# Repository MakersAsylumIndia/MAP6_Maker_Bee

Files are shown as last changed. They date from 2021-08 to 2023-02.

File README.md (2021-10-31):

# MAP6
Honey Bee shaped course ware for Maker's Asylum Electronics course.

**Maker's Asylum Project #6**

***FEATURES***

1. Two LED's with series current limit resistors
2. Two CR2032 Coin Battery or two CR2016 cells in a single 2032 holder
3. Vibration motor to move the honey bee.
4. 555 timer controls current flowing through transistor, resulting in "breathing LED" effect
5. Vibration motor intensity changes in sync with LED effect.
6. Use 555 as astable multivibrator with minor mods (see schematic)

***LEARN***

1. How to Solder
2. Resistor Color Code
3. Use of Multimeter to check LED, Resistor and Battery

SET UP A LINK -> DISCUSSION FORUM : http://discuss.makersasylum.com/t/map4-makers-asylum-learn-to-solder-badge/123

**Renders**
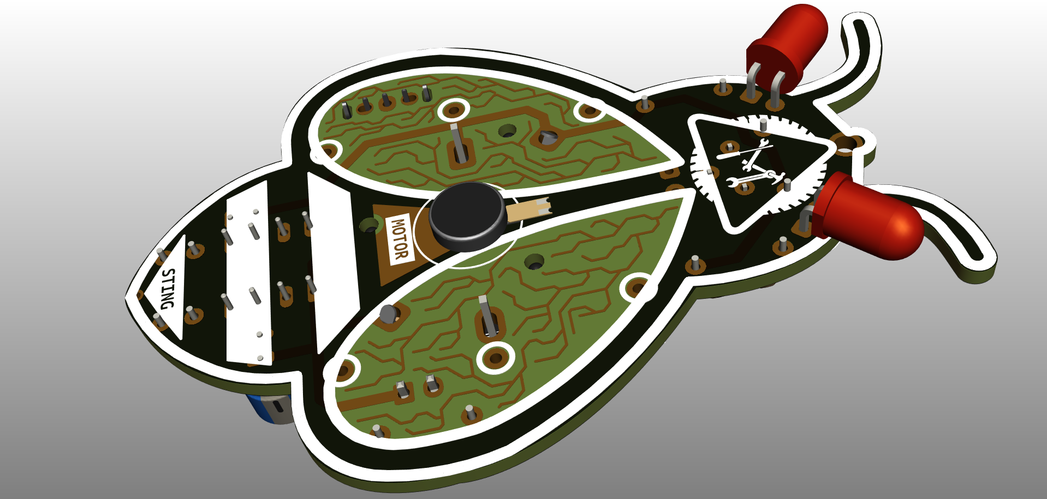
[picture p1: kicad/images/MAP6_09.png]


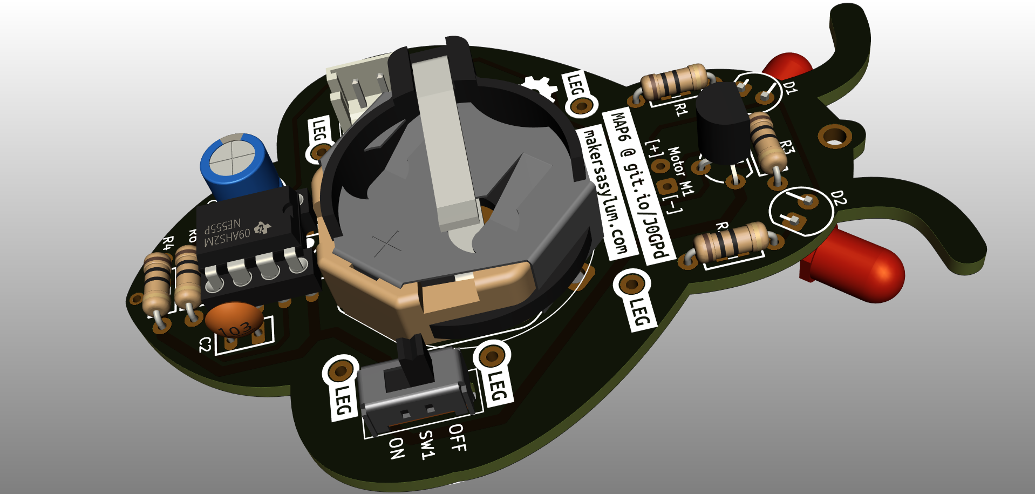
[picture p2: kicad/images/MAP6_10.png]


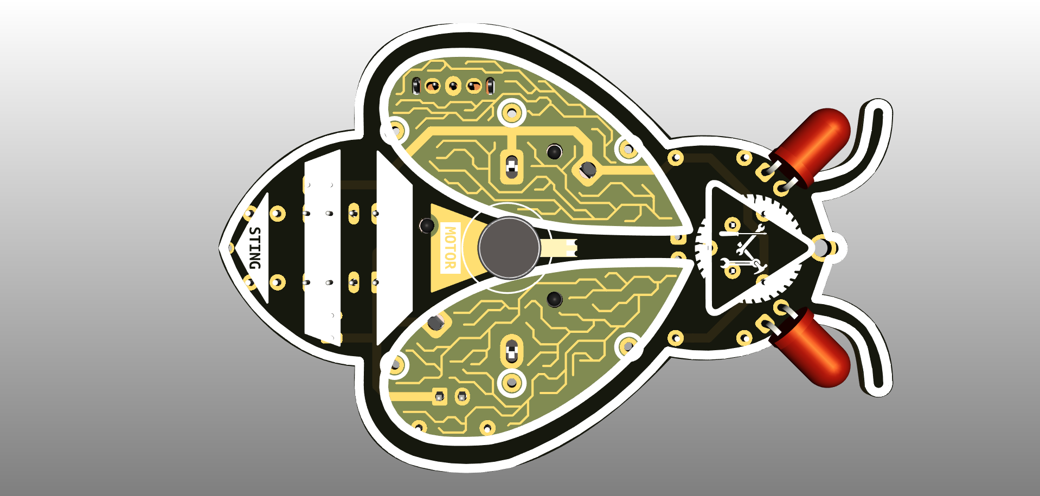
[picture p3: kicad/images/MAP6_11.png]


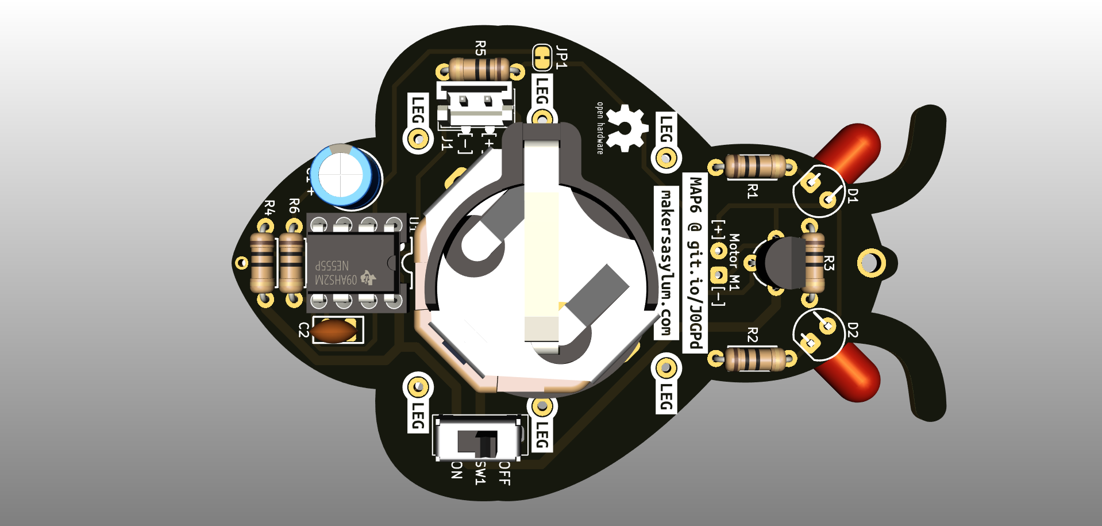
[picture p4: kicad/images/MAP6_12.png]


**Animation**
MAP6_gif

## OSHWA Certification

The **MAP6** "Maker Bee" is "Open Source Hardware" as certified by the [OSHWA](https://certification.oshwa.org/in000031.html).
OSHWA UID for the M19O2 is **IN000031**

<a href="https://certification.oshwa.org/in000031.html">OSHWA UID IN000031

License
-------

<a href="LICENSE.md">Open Source Licenses Facts</a>

[CERN Open Hardware Licence v1.2 ]

[CERN Open Hardware Licence v1.2 ]:http://www.ohwr.org/attachments/2388/cern_ohl_v_1_2.txt

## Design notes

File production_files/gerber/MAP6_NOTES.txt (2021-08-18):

1. Please place ETOK mark on BOTTOM LAYER in provided BOX.
2. SOLDER MASK COLOR : BLACK
3. LEGEND COLOR : YELLOW

OTHER REQUIREMENTS AS BELOW :

Layers 2 L
PCB Thickness(mm) 1.60 MM
PCB Dimensions 75 x 50 MM
PCBs/Panel 0
Top Solder Mask Black
Top Legend Yellow
TG Std. Tg ( 130-140 °)
Via Fill No
Carbon contacts No Carbon Contacts
Edge Connector 0.00
Blind & Buried Via NO
Electrical Testing Yes
Material FR4
Surface Finish HAL (Sn-Pb)
Start Cu Thickness 17.50
I/L Cu thickness 0.00
Finish Cu Thickness 35.00
Bottom Solder Mask Black
Bottom Legend Yellow
Layer Build-Up Standard
Peel Off No Peel Off
UL Logo No
Edge Connector Au Thickness
(μm) 0.00
Impedance Control No

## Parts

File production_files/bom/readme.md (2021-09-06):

To preview this HTML BoM directly in your browser, use this link :

https://htmlpreview.github.io/?https://github.com/MakersAsylumIndia/MAP6/blob/main/kicad/bom/MAP6_1.html

If you have already cloned the repository, you can view it in your browser locally.

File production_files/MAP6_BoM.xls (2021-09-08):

Id | Designator | Package | Quantity | Designation | NOTES | LINK | ROBU | ROBU price | Digikey P/N | Digikey price
 |  |  |  |  |  |  |  | ₹213.83 |  | ₹441.21 | @75INR/$ and 50% for shipping/customs
PCB PARTS
1 | BT1_holder |  | 1 | BAT_HOLDER | suitable for 2x2016 or 2x2032 | Option 1 (https://robu.in/product/2-x-cr2032-coin-button-cell-batteries-holder-with-on-off-switch/) | 975688 | ₹99.00
 |  |  |  |  |  | Option 2 (https://robu.in/product/cr2032-3v-button-coin-cell-battery-holder-case-box-with-on-off-switch-top-2-pcs/) | 975717
 |  |  |  |  |  | Option 3 (https://www.digikey.in/en/products/detail/mpd-memory-protection-devices/BH800S/221549) |  |  | BH800S-ND | $0.94
 |  |  |  |  |  | Option 4 (https://www.digikey.in/en/products/detail/keystone-electronics/3025-2/4499404) |  |  | 36-3025-2-ND
2 | C1 | CP_Radial_D6.3mm_P2.50mm | 1 | 47uF/16V | Capacitor, Electrolytic, 47uF, 16 V or more, 2.5 mm lead spacing, 6.3 mm diameter | LINK (https://robu.in/product/47-uf-16v-through-hole-electrolytic-capacitor-pack-of-40/) | 616602 | ₹1.12 | 732-9279-1-ND | $0.12
3 | C2 | C_Disc_D5.0mm_W2.5mm_P2.50mm | 1 | 10nF | Capacitor, Disc, 10nF, 2.5 mm lead spacing, 5 mm diameter | LINK | NA | ₹0.00 | C320C103K3G5TA-ND | $0.26
4 | D1 | LED-5MM_left | 1 | Red | Red LED, 5 mm | LINK (https://robu.in/product/everlight-5mm-red-dip-led/) | 872059 | ₹3.50 | C5SMF-RJF-CT0W0BB2CT-ND | $0.12
5 | D2 | LED-5MM_right | 1 | Red | Red LED, 5 mm | LINK (https://robu.in/product/everlight-5mm-red-dip-led/) | 872059 | ₹3.50 | C5SMF-RJF-CT0W0BB2CT-ND | $0.12
6 | M1 | motor_XDCR_C0720B001F | 1 | Motor_vibration | Vibration Motor, 10 mm | LINK (https://robu.in/product/flat-1027-mobile-phone-vibration-motor/) | 30624 | ₹82.00 | 1738-FIT0774-ND | $0.99
7 | Q1 | TO-92L_Wide | 1 | BC547 | Transistor, BC547 or equivalent NPN, TO-92 package | LINK (https://robu.in/product/bc547-npn-transistor-pack-of-20/) | 598304 | ₹1.95 | BC547ATACT-ND | $0.13
8 | R1,R2 | r_0805 | 2 | 220E | Resistor, 1/4 W, 220 E, axial or SMD | LINK (https://robu.in/product/220-ohm-resistor-0-25w-metal-film-pack-of-100/) | 582379 | ₹0.98 | CF18JT220RCT-ND | $0.02
9 | R3 | r_0805 | 1 | 47E | Resistor, 1/4 W, 47 E, axial or SMD | LINK (https://robu.in/product/47-ohm-0-25w-metal-film-resistor-pack-of-100/) | 583942 | ₹0.25 | CF18JA47R0CT-ND | $0.02
10 | R4 | r_0805 | 1 | 1k | Resistor, 1/4 W, 1k, axial or SMD | LINK (https://robu.in/product/1k-ohm-0-25w-metal-film-resistor-pack-of-100/) | 582209 | ₹0.49 | RNF18FTD1K00CT-ND | $0.03
11 | R5 | r_0805 | 1 | 33k | Resistor, 1/4 W, 33k, axial or SMD | LINK (https://robu.in/product/33k-ohm-0-25w-metal-film-resistor-pack-of-100/) | 582422 | ₹0.35 | CF18JT33K0CT-ND | $0.02
12 | R6 | r_0805 | 1 | 10k | Resistor, 1/4 W, 10k, axial or SMD | LINK (https://robu.in/product/10k-ohm-0-25w-metal-film-resistor-pack-of-100/) | 582314 | ₹0.49 | CF14JT10K0CT-ND | $0.01
13 | SW1 | SW_SPDT_Straight | 1 | On | Switch, PCB mount, or header pins with shorting link | LINK (https://robu.in/product/4mm-spdt-1p2t-slide-switch-pack-of-10/) | 578531 | ₹4.90 | CKN9565-ND | $0.41
14 | U1 | DIP-8_W7.62mm | 1 | LM555 | IC, LM555, DPI package | LINK (https://robu.in/product/ne-555-p-pdip-8-timer-ic-pack-of-5/) | 161997 | ₹9.80 | ICM7555IPAZ-ND | $0.59
15 | U1_socket | DIP-8_W7.62mm | 1 | DIP-8 socket | Socket for 8-pin DIP-8 package | LINK (https://robu.in/product/8-pin-dip-ic-socket-base-adaptor-pack-of-10/) | 534647 | ₹5.50 | AE9986-ND | $0.13
OTHER PARTS
16 | BT1 | cr2032_02 | 2 | BAT | Use 2 nos 2032 | LINK (https://robu.in/product/panasonic-cr2032-3v-lithium-coin-battery-2pcs/) | 352755 | ₹39.50
17 | LEGS | Brass Wire, 0.8 ~ 0.9 mm | 6 | -- | 6 pieces, each about 3-4 inches long | Amazon (https://www.amazon.in/s?k=Brass+Jewellery+Wire&ref=nb_sb_noss)

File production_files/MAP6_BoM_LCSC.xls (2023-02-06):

Quantity | Manufacture Part Number | Manufacturer(optional) | Description(optional) | LCSC Part Number(optional) | Package(optional) | Customer Part Number(optional)
1 | KM476M035E11RR0VH2FP0
1 | CC1H103ZA1FD3F4D1001
2 | XL-502SURD
1 | LCM1027A2445F
1 | BC547CBK
2 | MFR-25FTE52-220R
1 | MFR2WSFTE73-47R
1 | MFR50SFTE52-1K
1 | MFR-25JT-52-33K
1 | MFR-25FTE52-10K
1 | SS-12D02G3
1 | NE555L-D08-T
1 | DS1009-08AT1NX-0A2

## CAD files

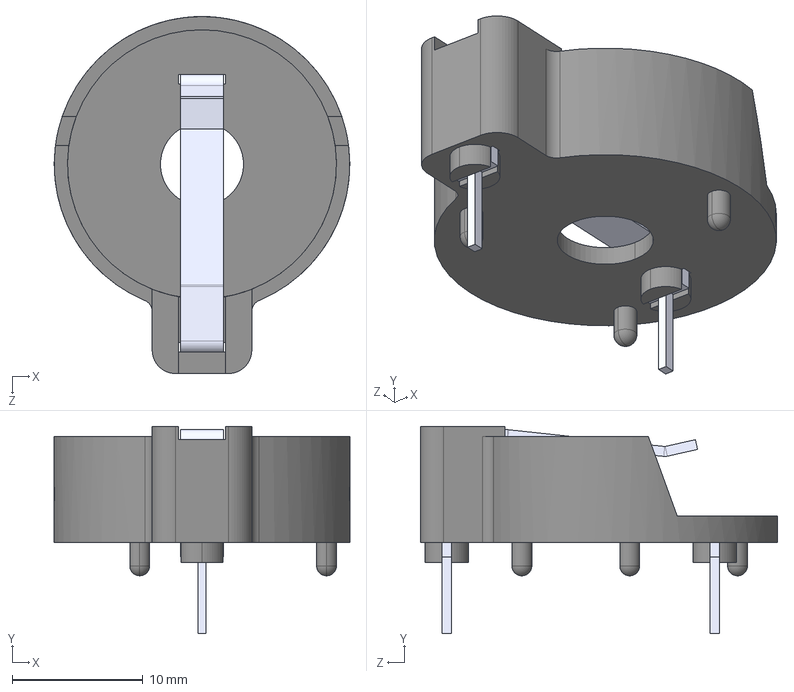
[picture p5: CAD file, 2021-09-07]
datasheets/BH800S/BH800S.step
22.6 x 15.8 x 27.3 mm

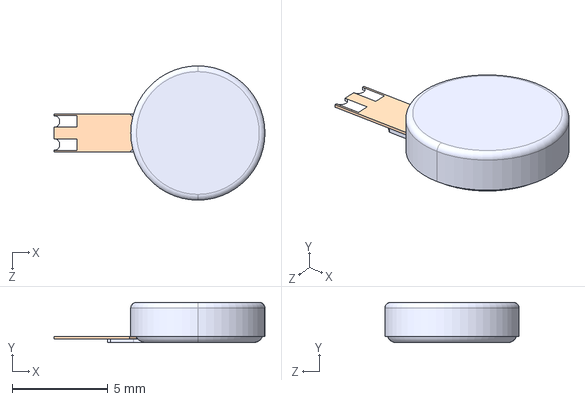
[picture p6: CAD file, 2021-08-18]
datasheets/C0720B001F/C0720B001F.step
11.0 x 2.10 x 7.00 mm

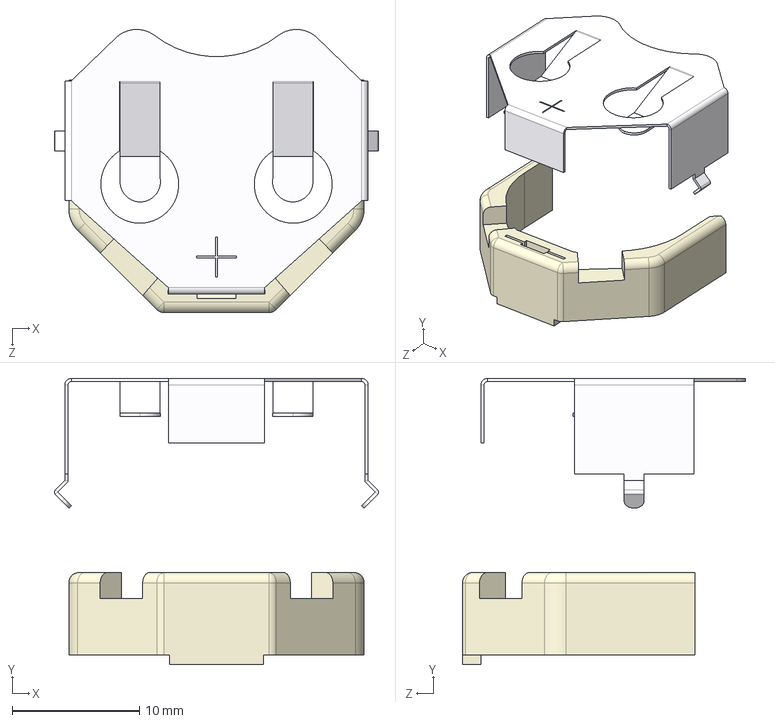
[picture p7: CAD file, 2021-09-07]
datasheets/keystone-PN3025-2.step
25.5 x 22.5 x 22.3 mm

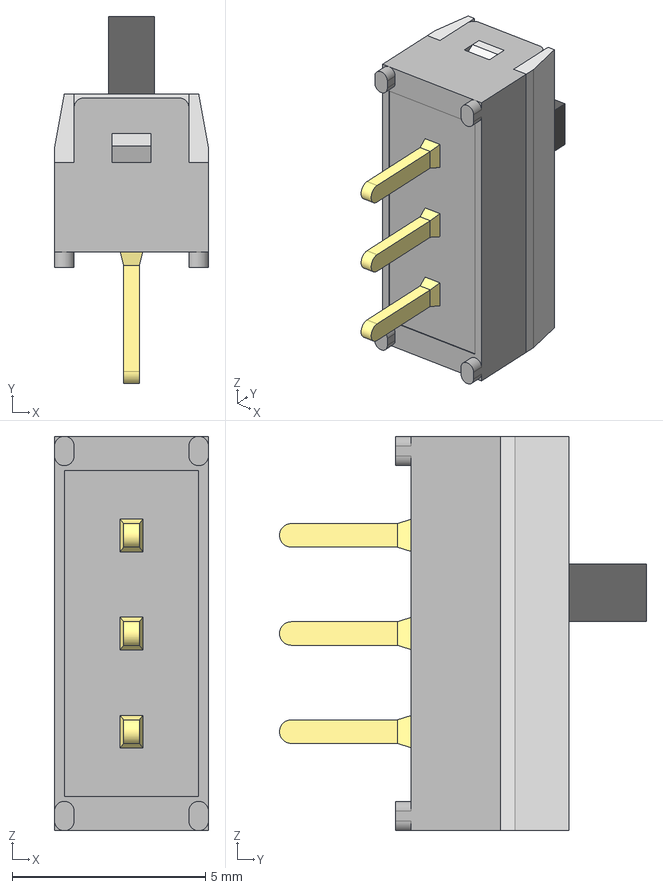
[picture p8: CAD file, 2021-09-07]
datasheets/NKKSWITCHES_SS12SDP4/SS12SDP4.stp
3.99 x 9.50 x 10.2 mm
_SS12SDP4body2
_SS12SDP4trmd
_SS12SDP4body1
_SS12SDP4actut

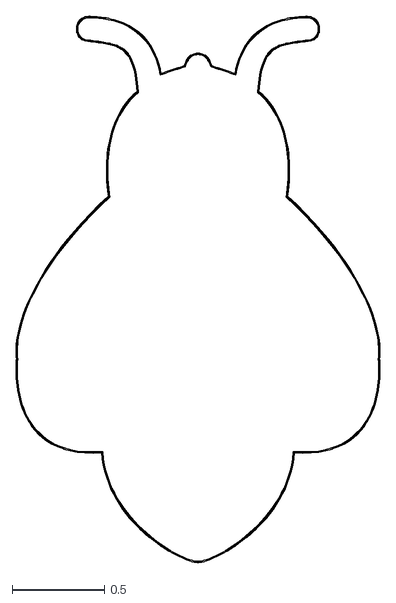
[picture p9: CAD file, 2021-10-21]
fabricate/dxf_files/MAP6-Edge_Cuts.dxf
1.97 x 2.95

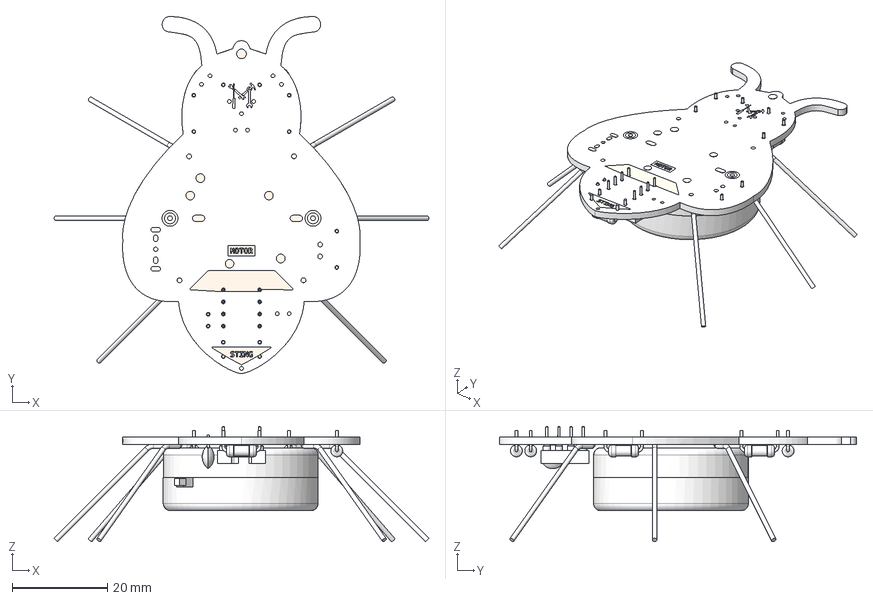
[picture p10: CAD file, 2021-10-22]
fabricate/MAP6_CAD2.FCStd
78.6 x 74.9 x 24.2 mm
Pcb_25ad
topSilks_fa88
botSilks_3b4e
C2_C_Disc_D50mm_W25mm_P250mm001_6139262A
DIP_8_W762mm_Socket
Top

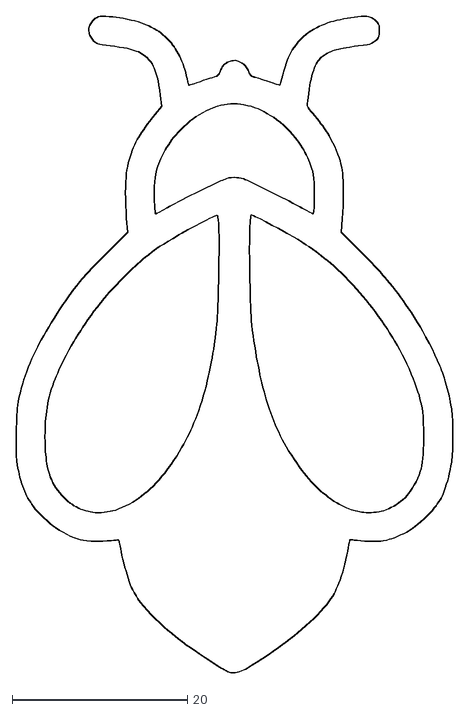
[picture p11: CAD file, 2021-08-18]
fabricate/PCB_outline/shape_bee6.dxf
49.8 x 74.9

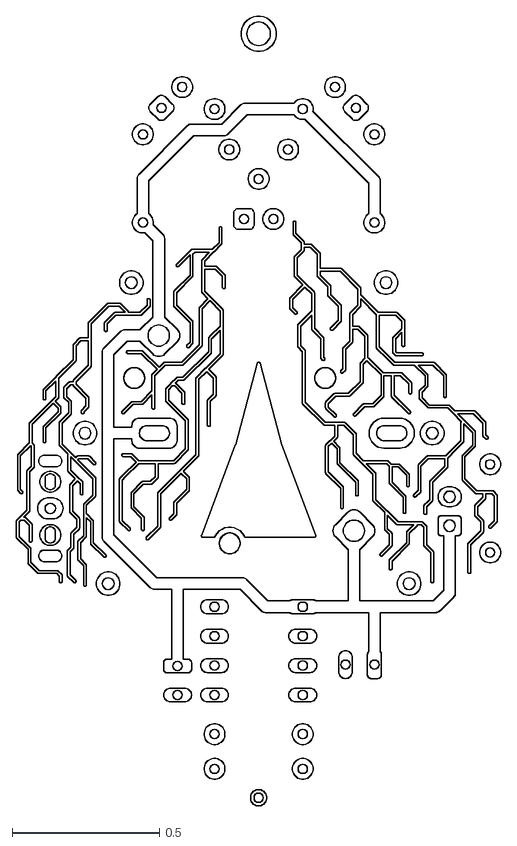
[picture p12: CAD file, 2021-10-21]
fabricate/dxf_files/MAP6-F_Cu.dxf
1.65 x 2.69

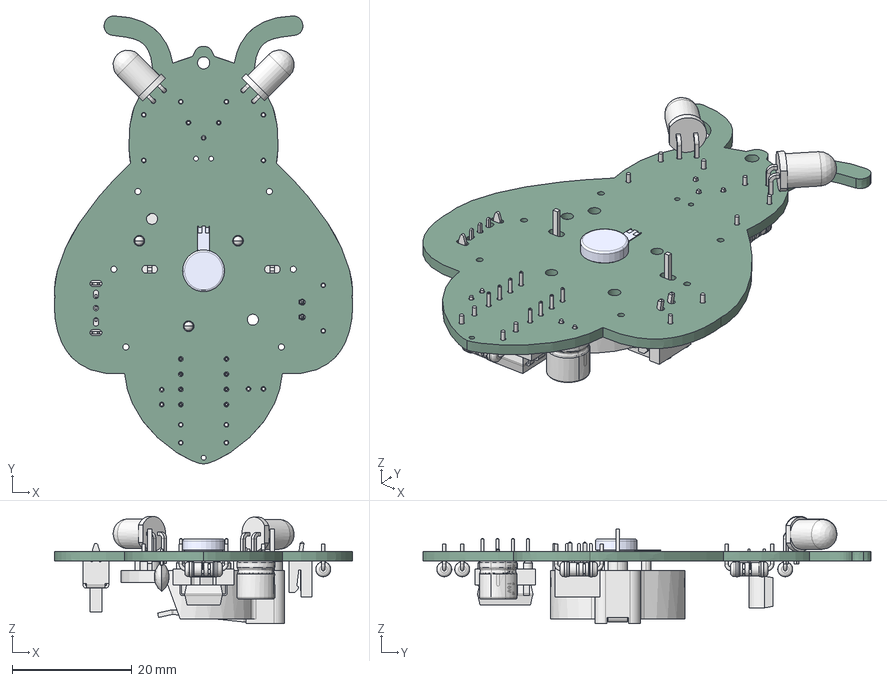
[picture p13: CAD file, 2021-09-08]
fabricate/MAP6_CAD.FCStd
49.9 x 74.9 x 17.9 mm
Pcb_25ad
C0720B001F
C0720B001F001
C0720B001F002
C0720B001F003
C0720B001F004
C1_CP_Radial_D63mm_P250mm001_6139076A
C2_C_Disc_D50mm_W25mm_P250mm001_6139262A
U1_DIP-8_W7.62mm_611AD7C5
J1_JST_B2B_EH_A_61394347

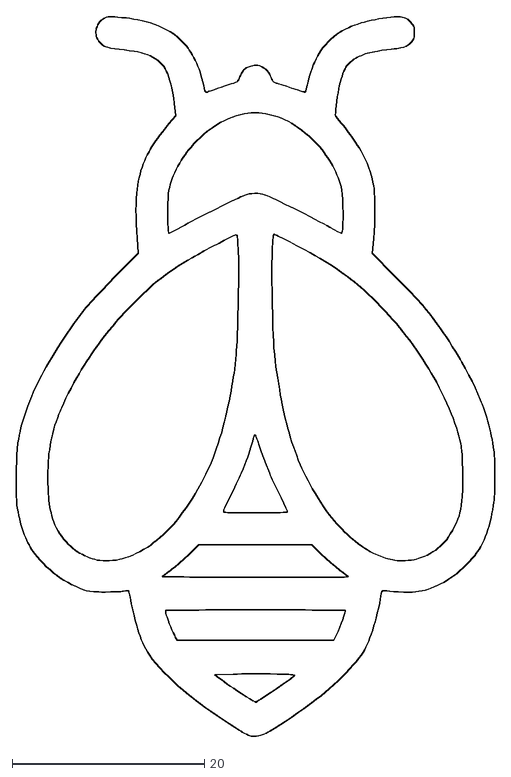
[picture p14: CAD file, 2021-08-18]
fabricate/PCB_outline/shape_bee.dxf
49.8 x 74.9

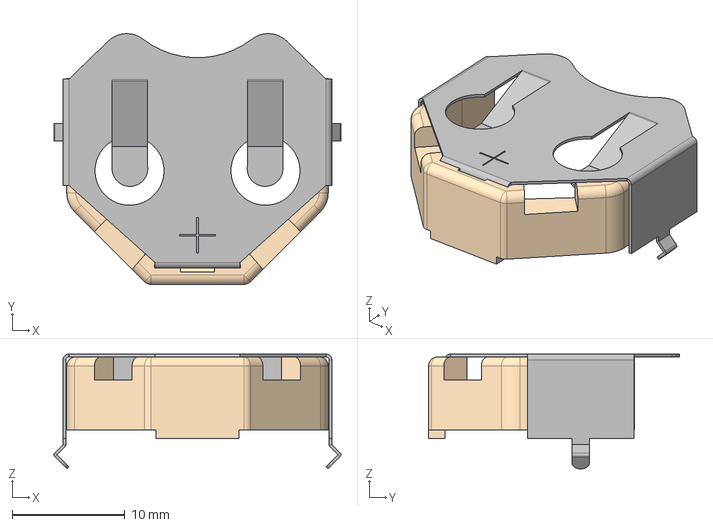
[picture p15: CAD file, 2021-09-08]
kicad/3d_modules/CR2032_3025-2.step
25.5 x 22.3 x 10.2 mm

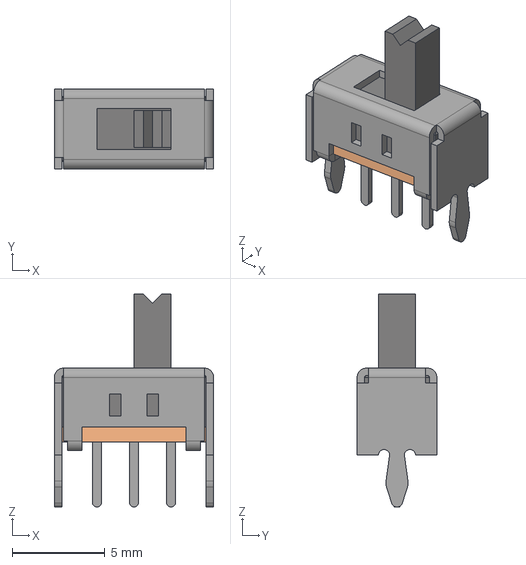
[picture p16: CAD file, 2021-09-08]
nightly/3d_modules/SW_OS102011MS2QN007.step
8.60 x 4.30 x 11.5 mm

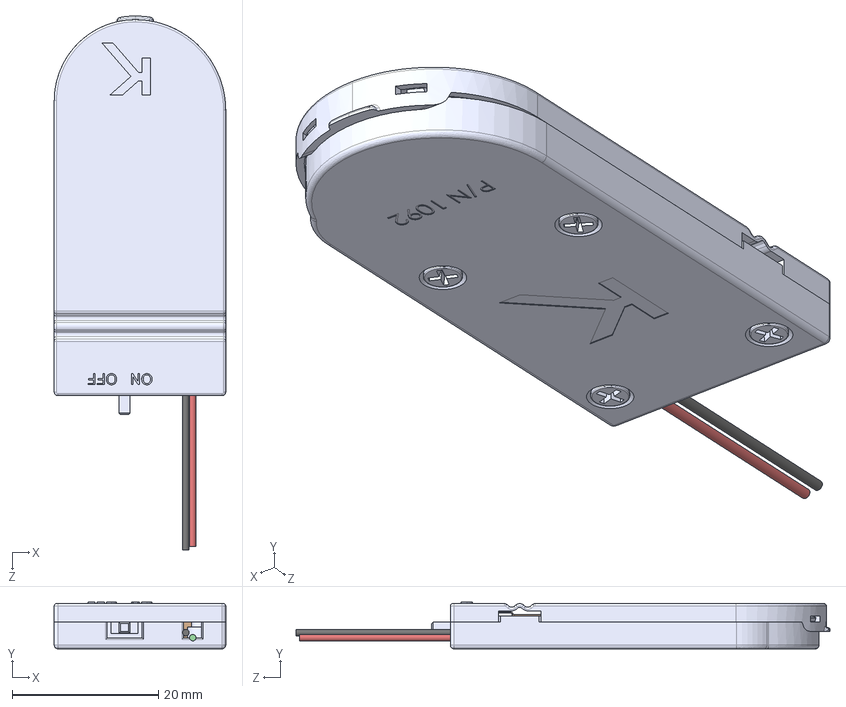
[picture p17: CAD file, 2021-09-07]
datasheets/keystone-PN1092.step
23.5 x 6.40 x 73.1 mm
SCREW-2032______ANY_ANY_ANY x 4
1092_switch-1.SLDASM
1092_switch-2
F1092-2
F1092-1
1092_base
1092_cover
F1092-3
26 AWG BLACK WIRE for 1086
26 AWG RED WIRE ror 1086

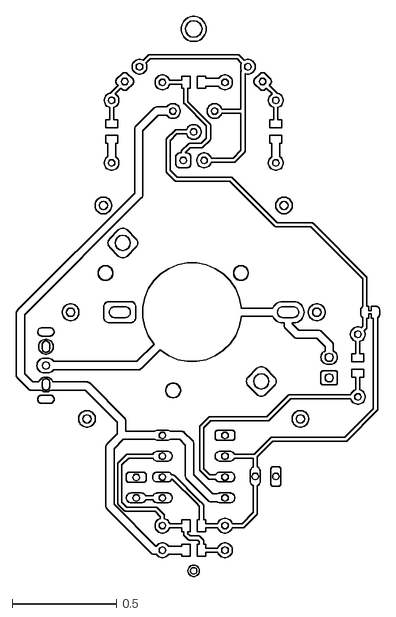
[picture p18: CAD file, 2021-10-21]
fabricate/dxf_files/MAP6-B_Cu.dxf
1.74 x 2.69

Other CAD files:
kicad/3d_modules/CR2032_BH800S.step
nightly/3d_modules/CR2032_BH800S.step
fabricate/PCB_outline/shape_bee5.dxf
datasheets/OS102011MS2QN1/OS102011MS2QN1.step
fabricate/PCB_outline/outline_bee.dxf
fabricate/PCB_outline/outline_bee2.dxf
fabricate/PCB_outline/shape_bee2.dxf
fabricate/PCB_outline/shape_bee3.dxf
fabricate/PCB_outline/shape_bee4.dxf
fabricate/dxf_files/MAP6-B_Mask.dxf
fabricate/dxf_files/MAP6-B_SilkS.dxf
fabricate/dxf_files/MAP6-F_Mask.dxf
fabricate/dxf_files/MAP6-F_SilkS.dxf
kicad/3d_modules/CR2032_cyl_cp.step
kicad/3d_modules/JST_EH_B2B-EH-A_1x02_P2.50mm_Vertical.step
kicad/3d_modules/SW_SS12SDP4.step
nightly/3d_modules/2x2032_cyl.FCStd
nightly/3d_modules/2x2032_cyl.step
nightly/3d_modules/BATTERY_HOLDER_CR2032.step
nightly/3d_modules/CP_Radial_D63mm_P250mm.step
nightly/3d_modules/CP_Radial_D63mm_P250mm_FC.step
nightly/3d_modules/CP_Radial_D63mm_P25mm.FCStd
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

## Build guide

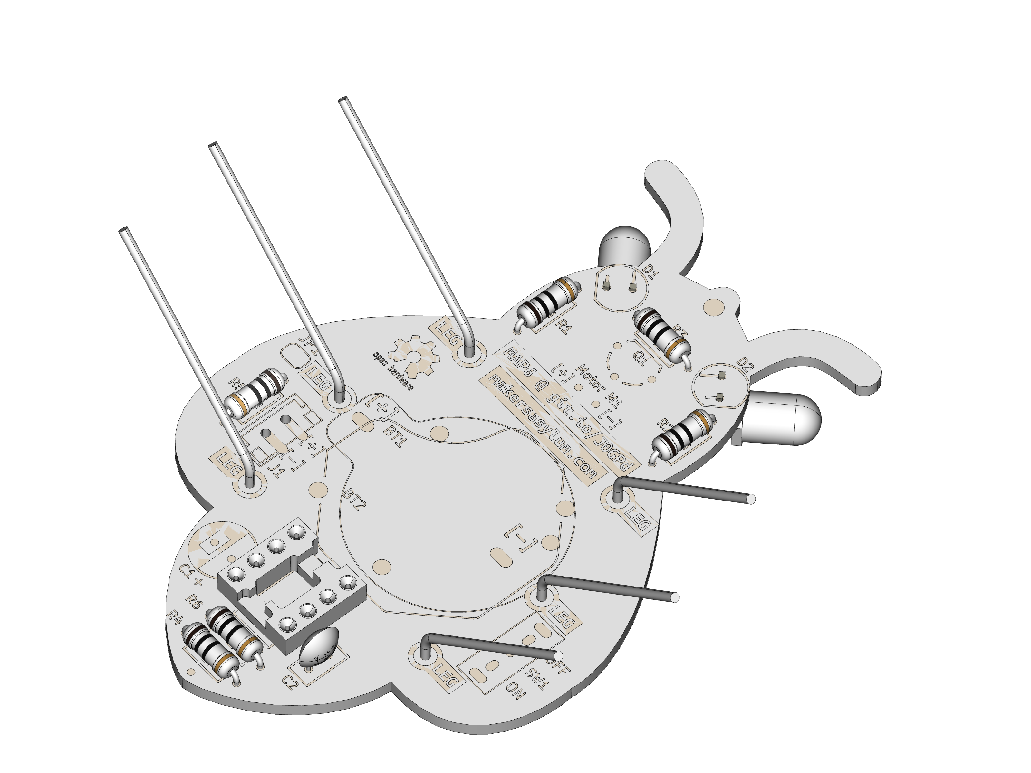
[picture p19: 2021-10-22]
fabricate/images/MAP6_assy_23.png

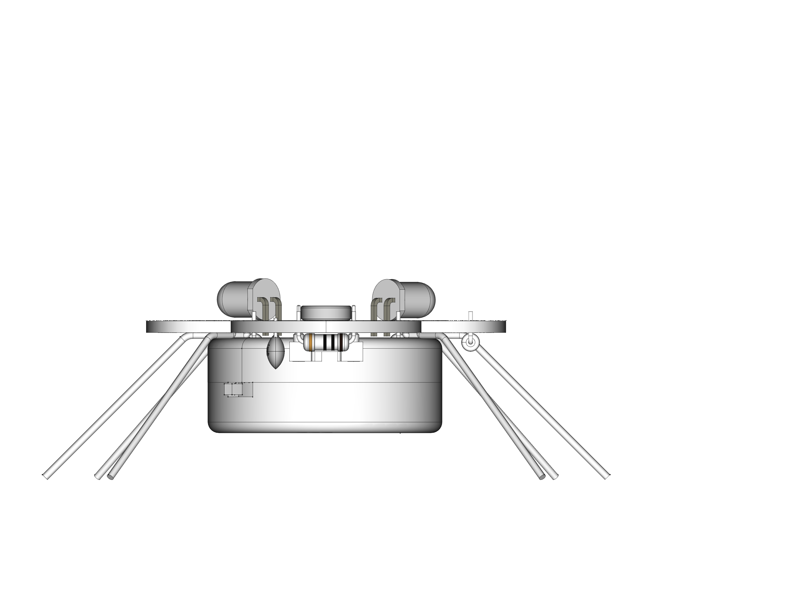
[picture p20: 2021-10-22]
fabricate/images/MAP6_assy_31.png

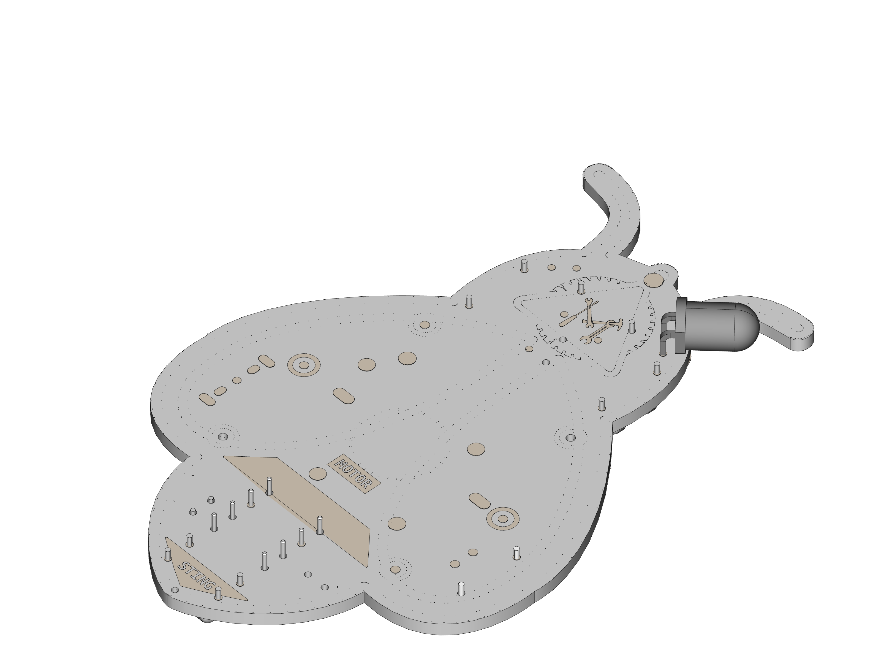
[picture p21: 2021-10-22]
fabricate/images/MAP6_assy_16.png

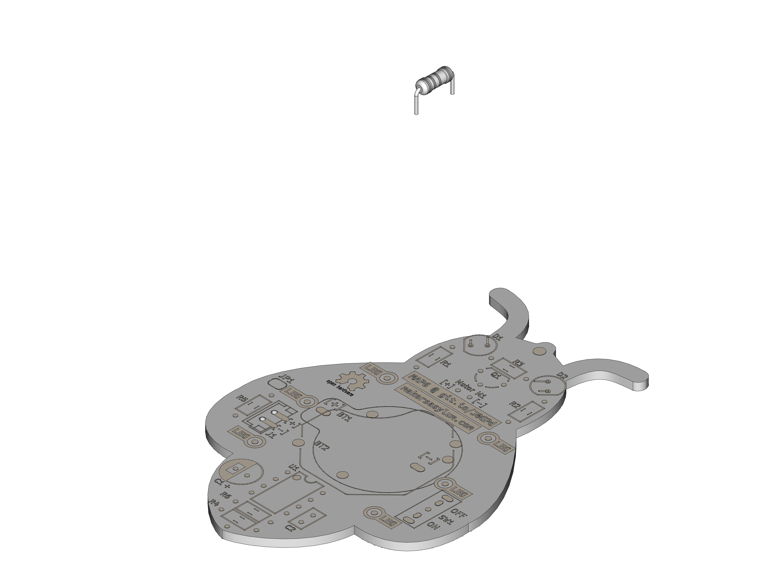
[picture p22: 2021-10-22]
fabricate/images/MAP6_assy_02.png

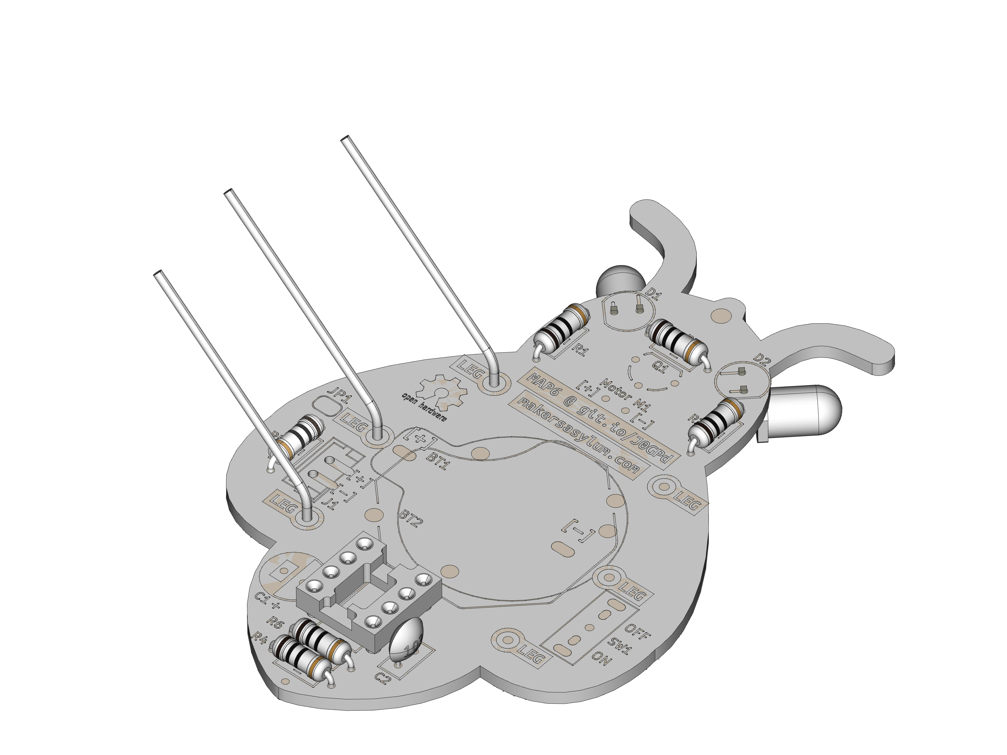
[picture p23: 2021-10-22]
fabricate/images/MAP6_assy_22.png

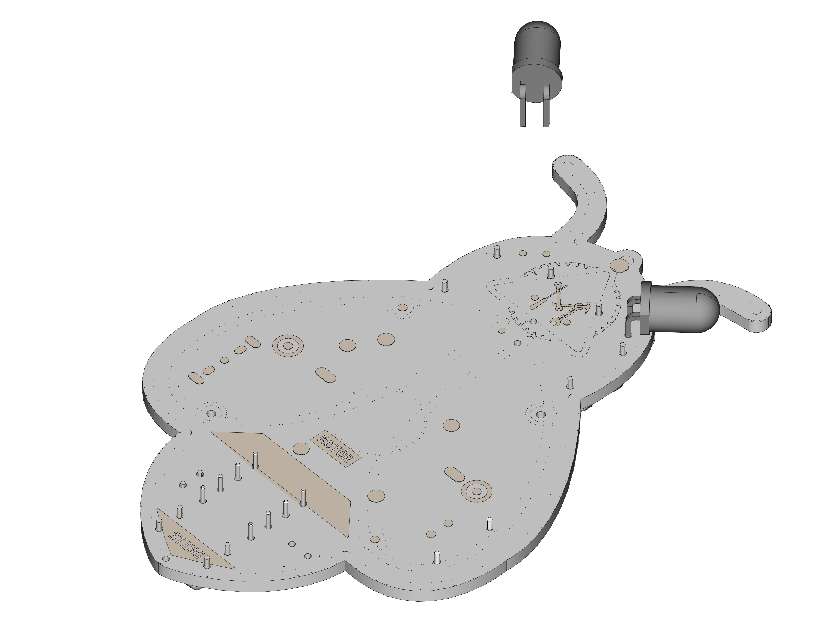
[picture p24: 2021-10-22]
fabricate/images/MAP6_assy_17.png

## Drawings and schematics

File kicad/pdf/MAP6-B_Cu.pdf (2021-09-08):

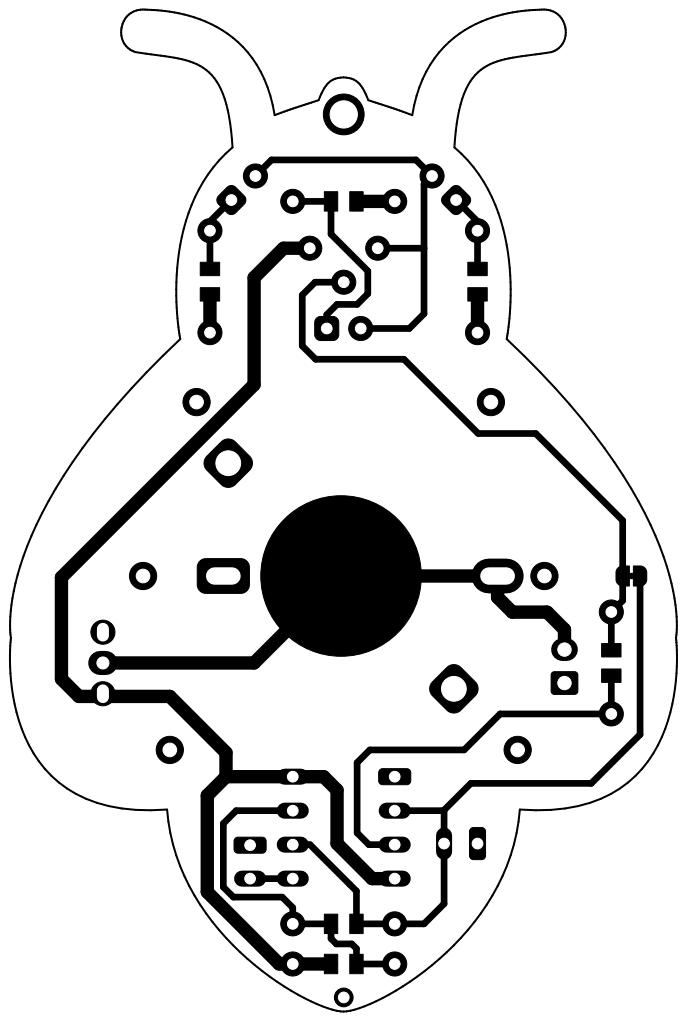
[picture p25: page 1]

Learn to Solder Maker's Asylum Badge
File: MAP6.kicad_pcb Sheet: Maker's Asylum

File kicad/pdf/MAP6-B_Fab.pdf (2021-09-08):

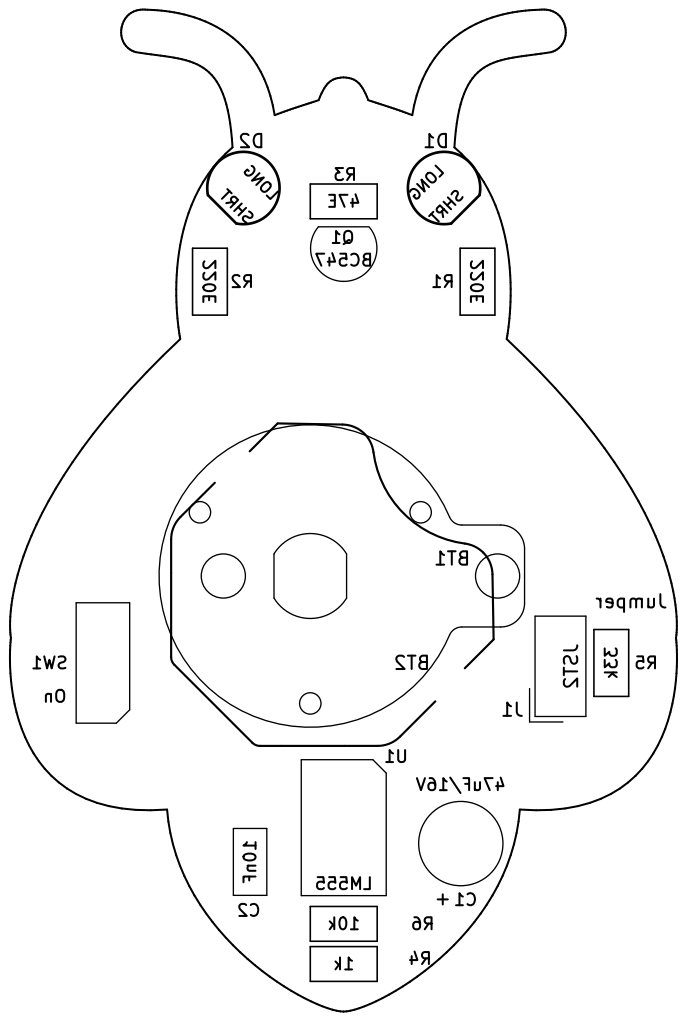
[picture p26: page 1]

Learn to Solder Maker's Asylum Badge
File: MAP6.kicad_pcb Sheet: Maker's Asylum

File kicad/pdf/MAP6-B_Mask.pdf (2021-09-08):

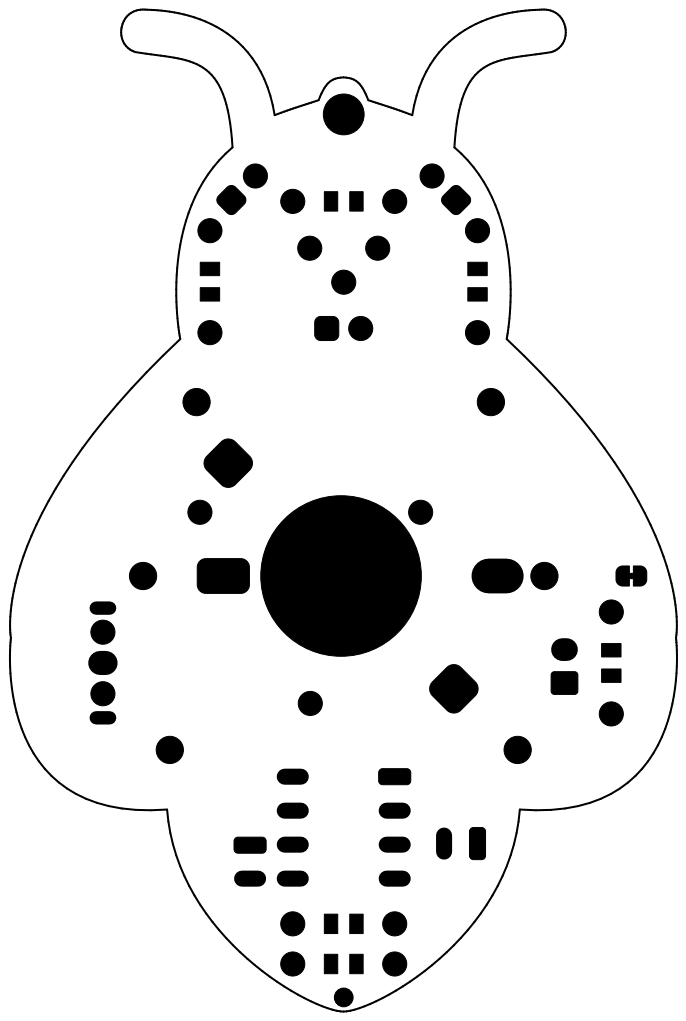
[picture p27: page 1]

Learn to Solder Maker's Asylum Badge
File: MAP6.kicad_pcb Sheet: Maker's Asylum

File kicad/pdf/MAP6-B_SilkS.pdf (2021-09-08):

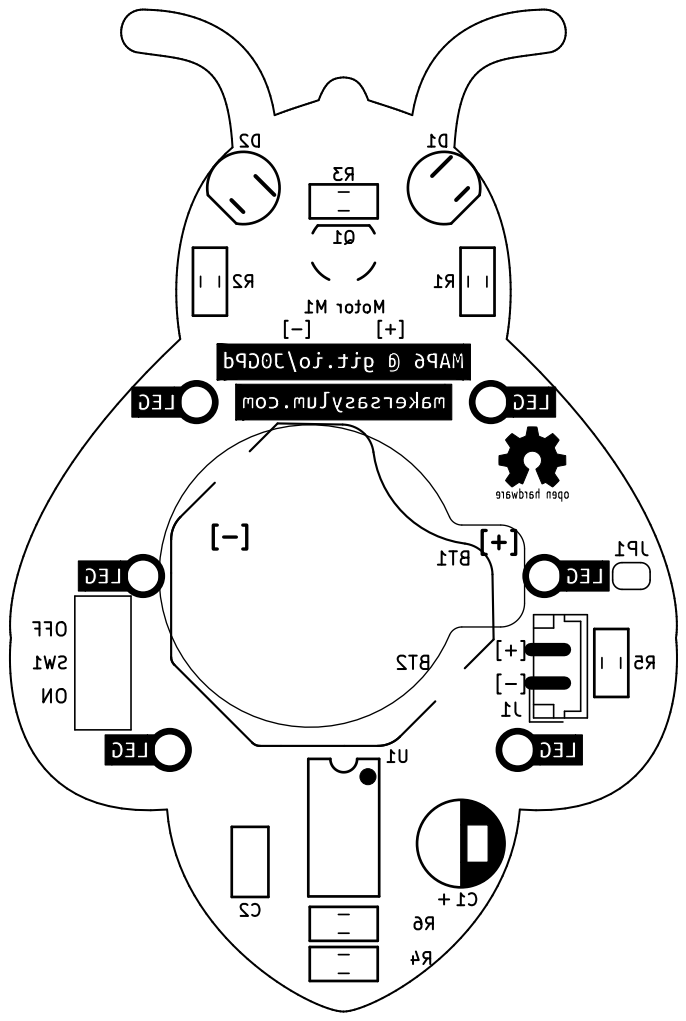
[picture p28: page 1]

Learn to Solder Maker's Asylum Badge
File: MAP6.kicad_pcb Sheet: Maker's Asylum

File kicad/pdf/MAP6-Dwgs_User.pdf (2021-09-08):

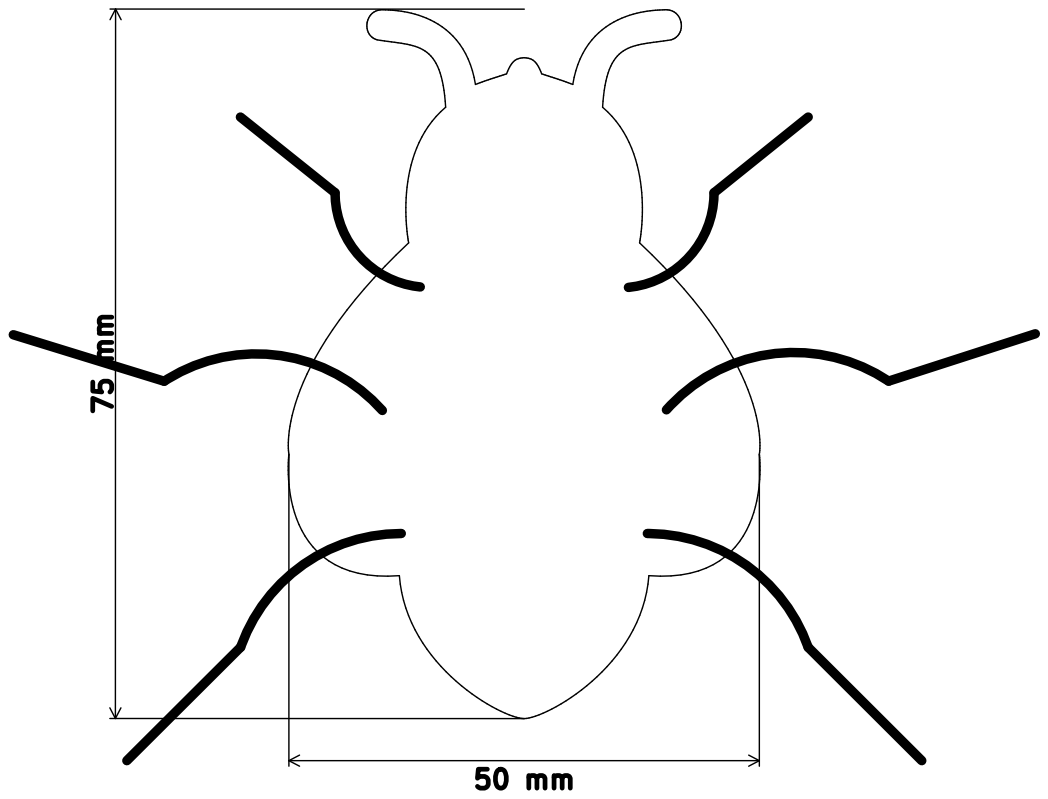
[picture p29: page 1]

Learn to Solder Maker's Asylum Badge 75 mm

File: MAP6.kicad_pcb Sheet: Maker's Asylum

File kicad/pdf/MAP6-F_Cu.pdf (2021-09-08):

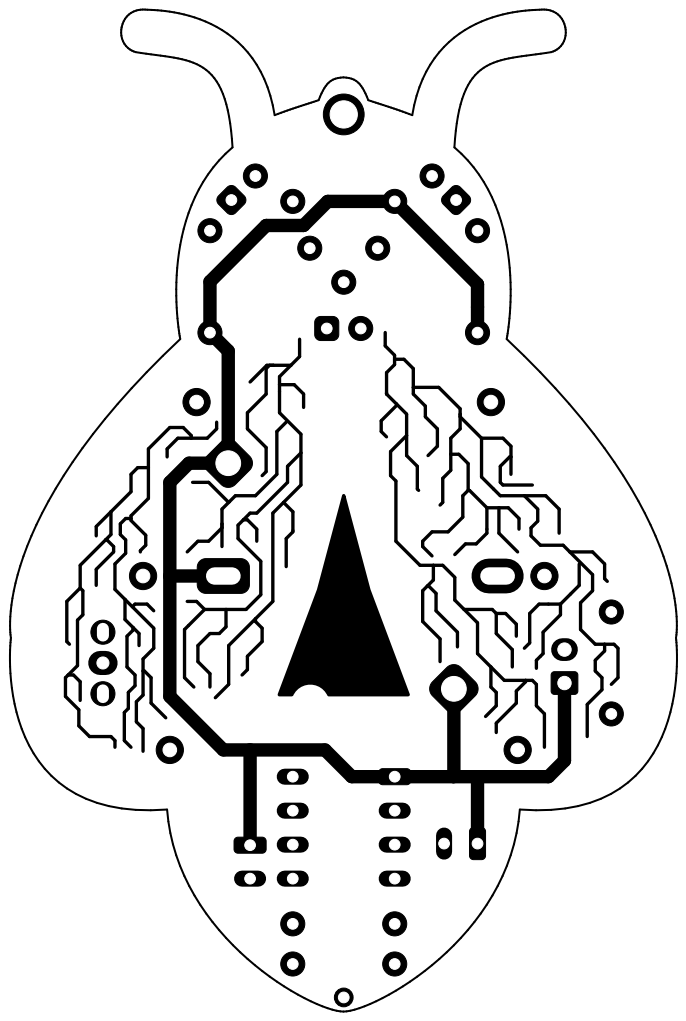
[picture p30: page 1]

Learn to Solder Maker's Asylum Badge
File: MAP6.kicad_pcb Sheet: Maker's Asylum

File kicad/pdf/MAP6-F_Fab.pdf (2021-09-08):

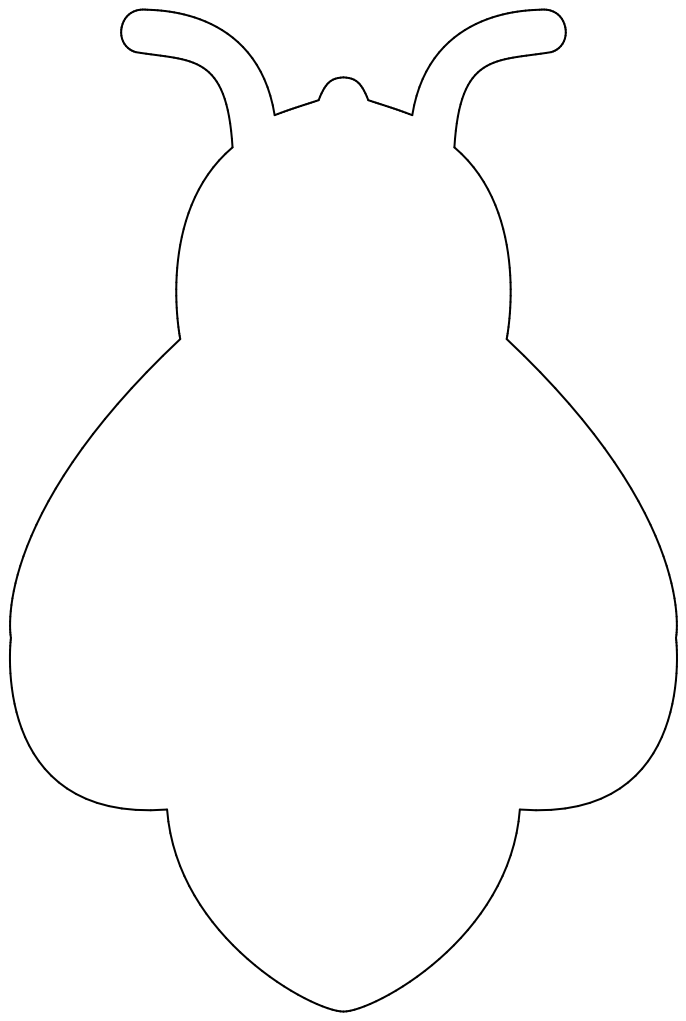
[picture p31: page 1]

Learn to Solder Maker's Asylum Badge
File: MAP6.kicad_pcb Sheet: Maker's Asylum

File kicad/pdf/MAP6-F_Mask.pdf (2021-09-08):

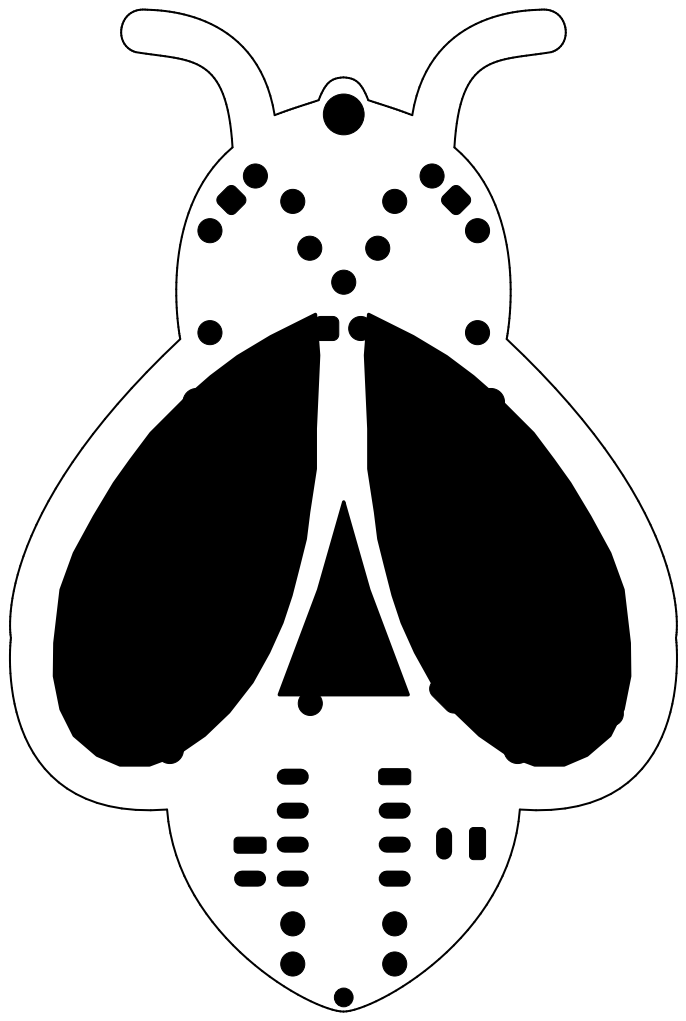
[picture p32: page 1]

Learn to Solder Maker's Asylum Badge
File: MAP6.kicad_pcb Sheet: Maker's Asylum

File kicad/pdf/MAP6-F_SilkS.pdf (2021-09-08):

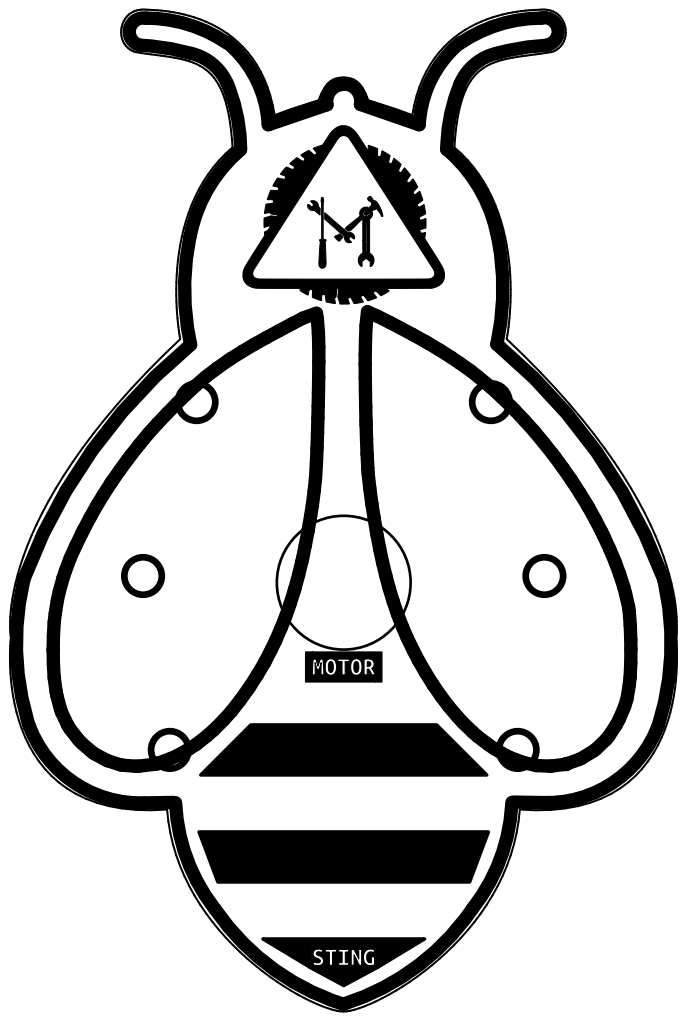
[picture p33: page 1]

Learn to Solder Maker's Asylum Badge
File: MAP6.kicad_pcb Sheet: Maker's Asylum

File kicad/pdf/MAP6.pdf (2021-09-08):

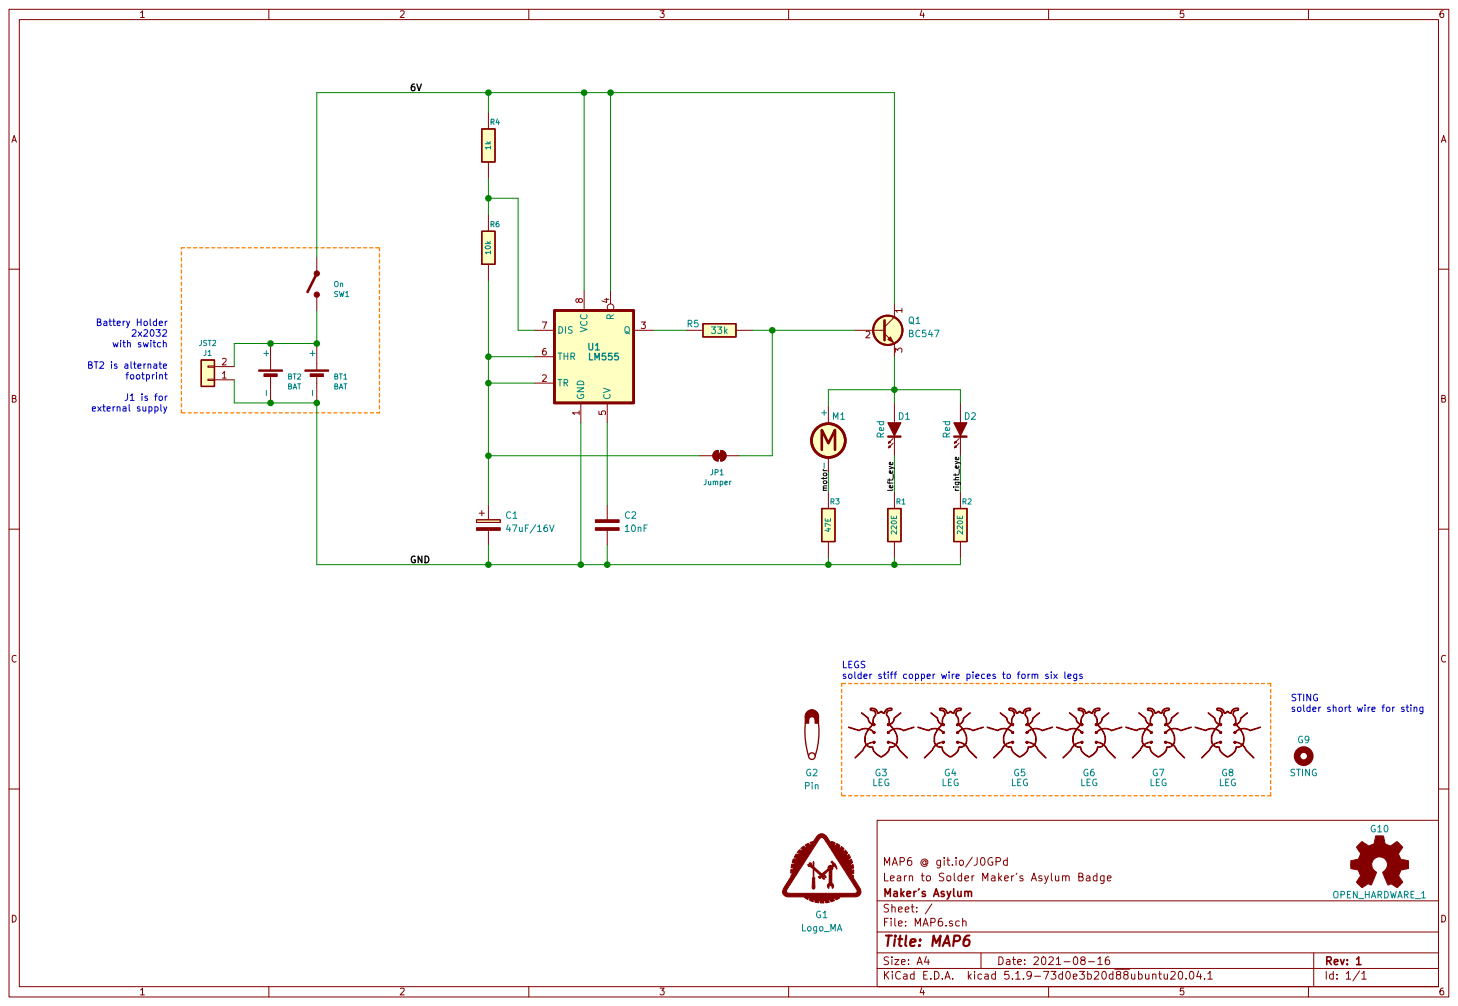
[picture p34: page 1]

Battery Holder 2x2032 with switch BT2 is alternate

solder stiff copper wire pieces to form six legs

solder short wire for sting

Learn to Solder Maker's Asylum Badge
File: MAP6.sch Sheet: / Maker's Asylum

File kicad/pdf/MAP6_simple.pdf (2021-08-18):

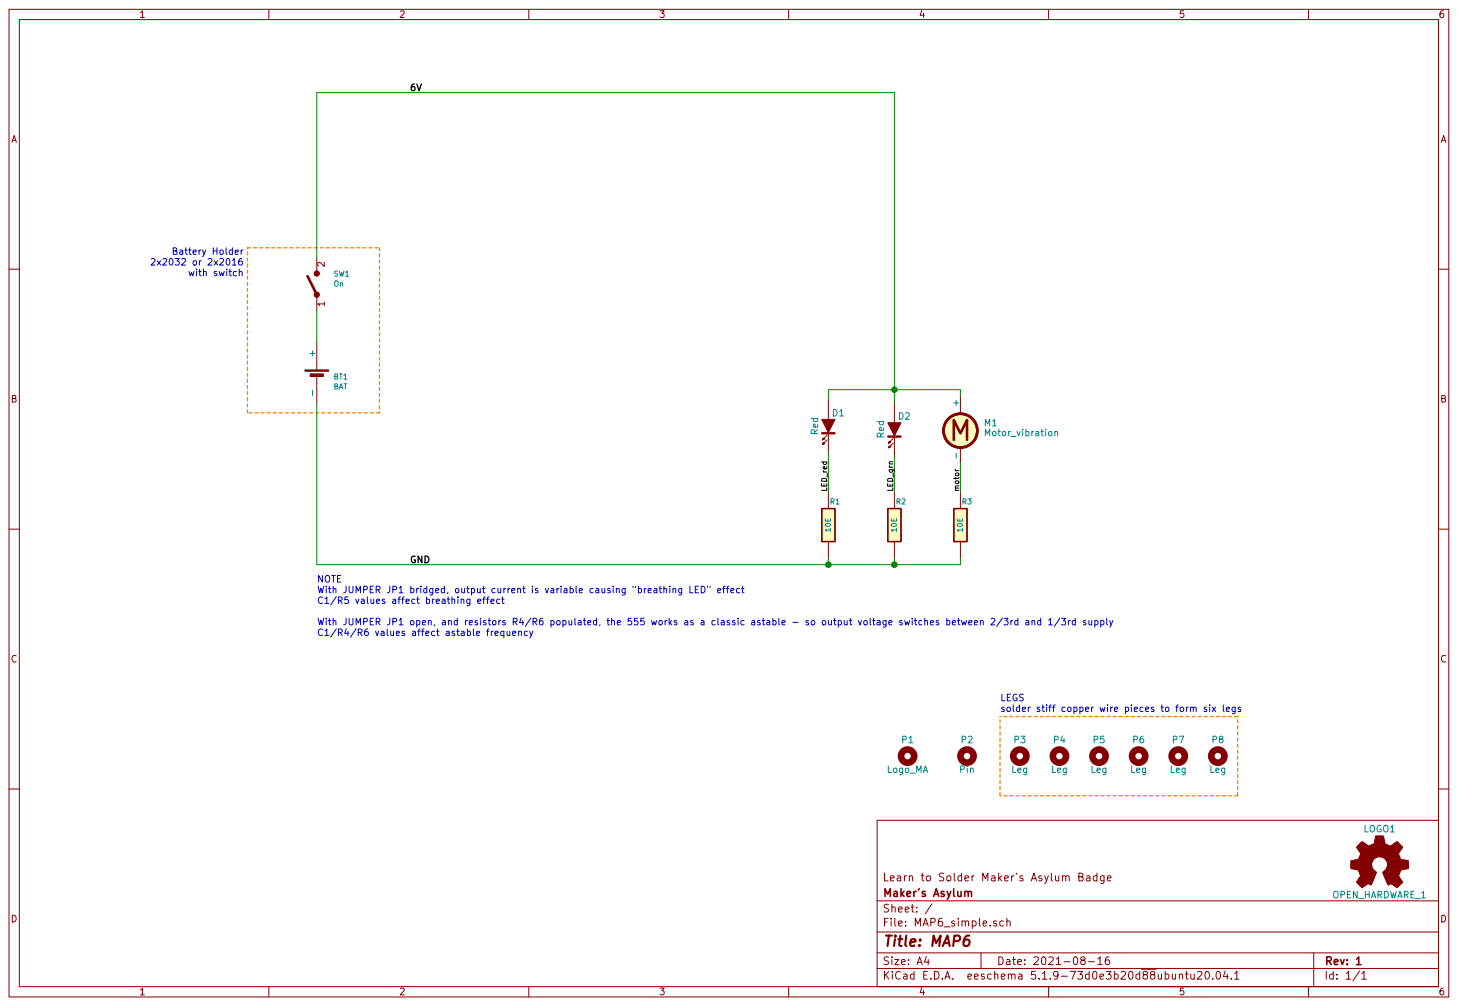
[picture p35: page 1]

Battery Holder 2x2032 or 2x2016 with switch

solder stiff copper wire pieces to form six legs NOTE With JUMPER JP1 bridged, output current is variable causing "breathing LED" effect

C1/R5 values affect breathing effect

With JUMPER JP1 open, and resistors R4/R6 populated, the 555 works as a classic astable - so output voltage switches between 2/3rd and 1/3rd supply
C1/R4/R6 values affect astable frequency

Learn to Solder Maker's Asylum Badge
File: MAP6_simple.sch Sheet: / Maker's Asylum

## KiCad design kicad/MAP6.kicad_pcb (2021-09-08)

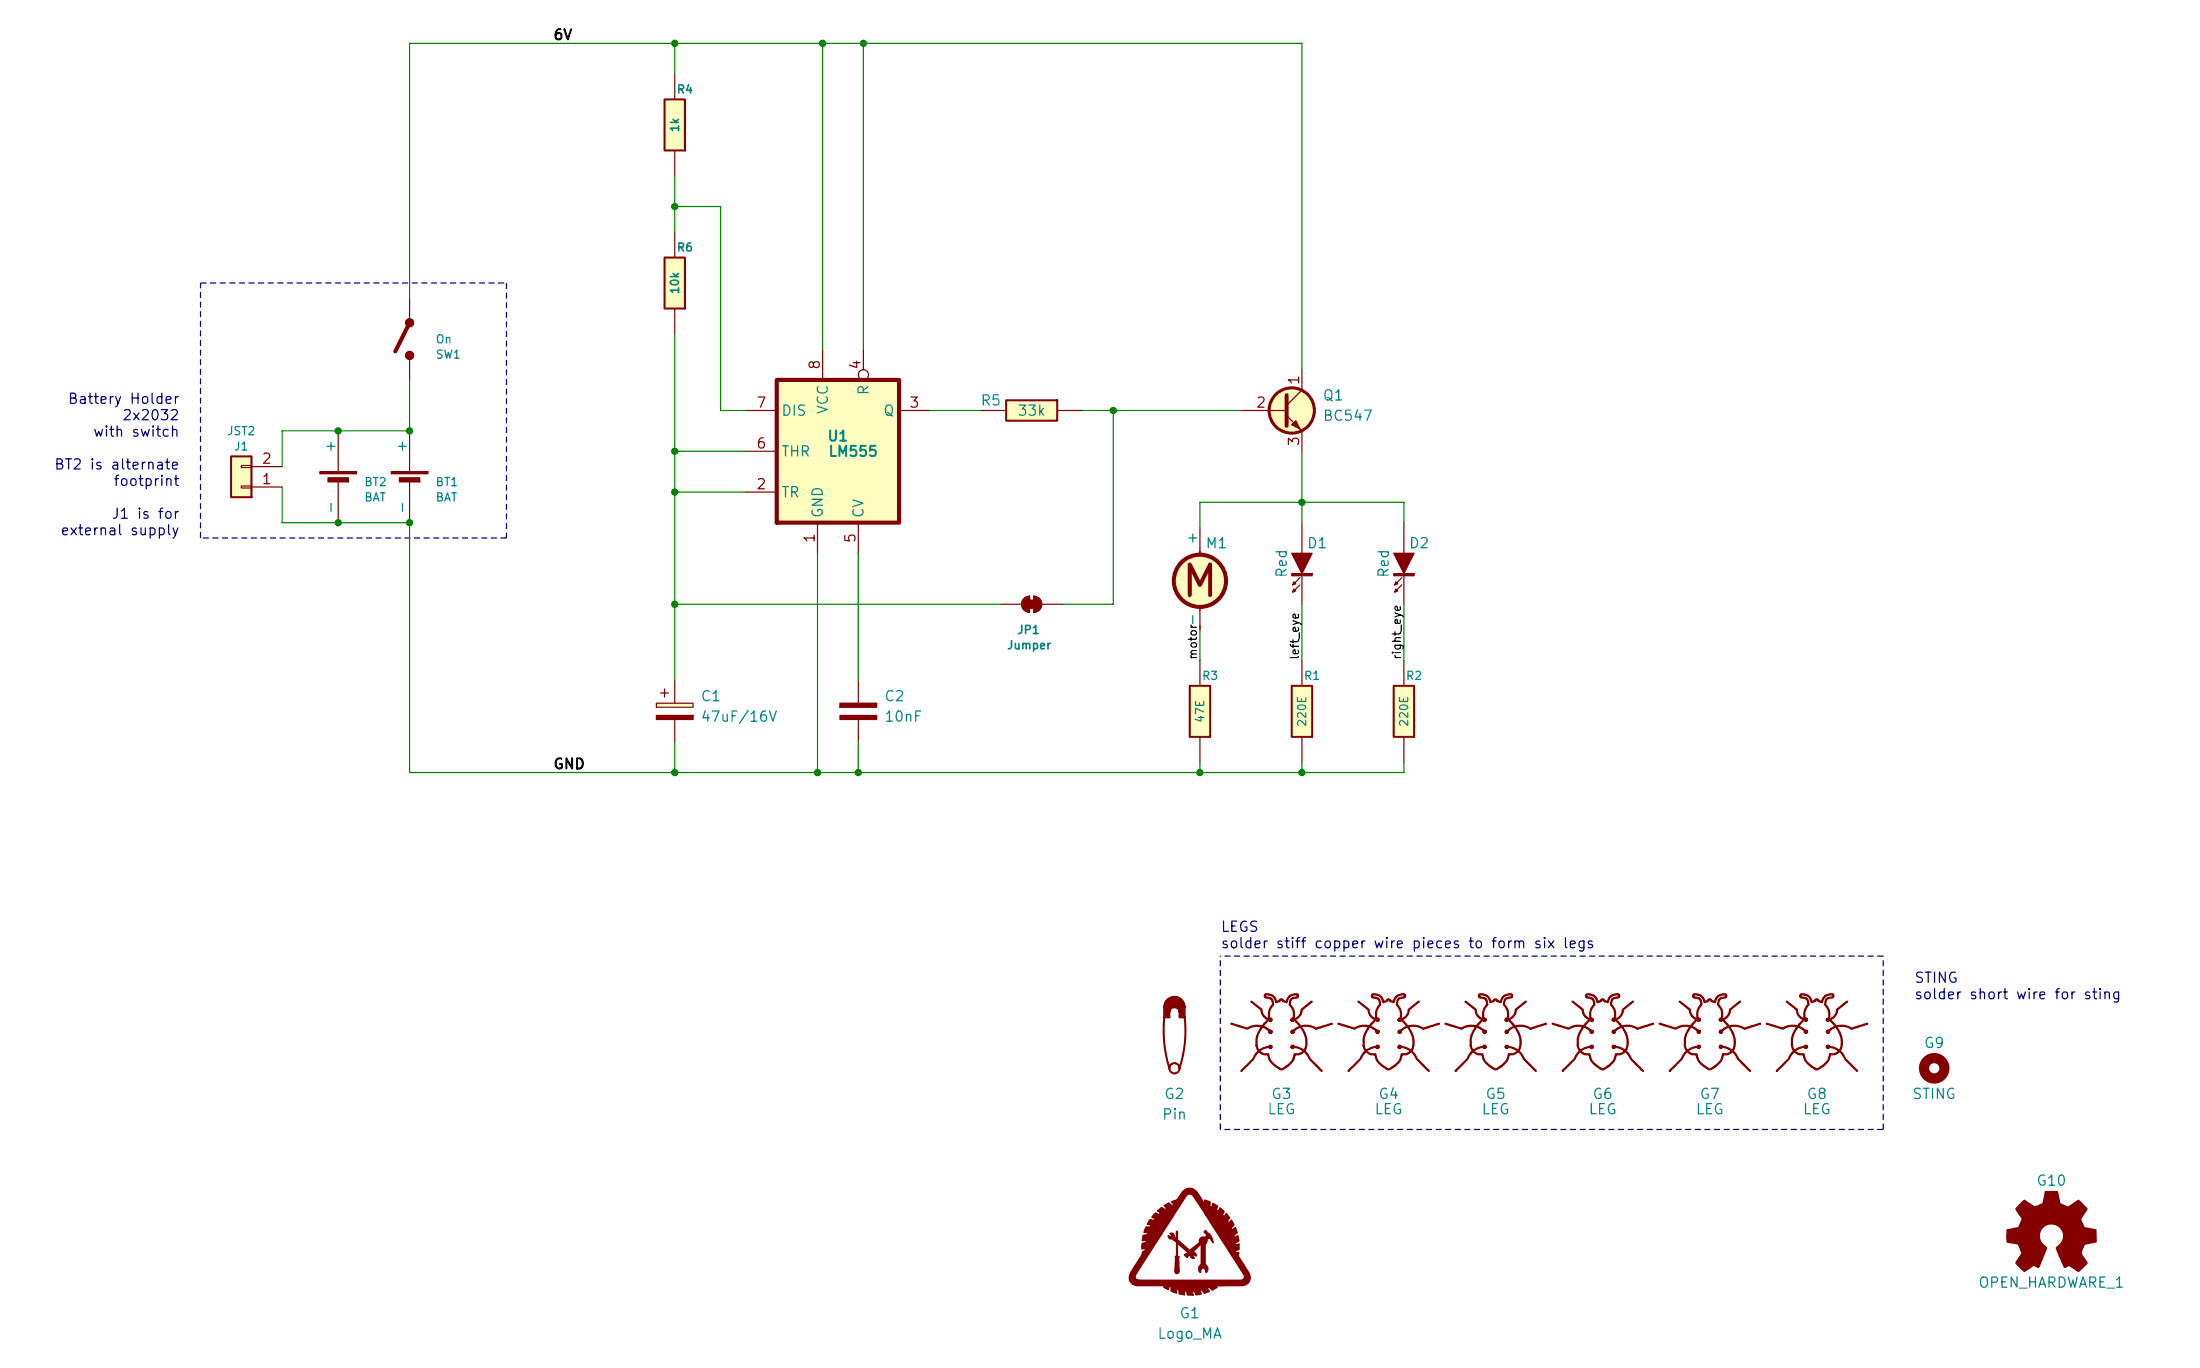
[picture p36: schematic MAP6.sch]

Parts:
BT1: BAT; cr2032_03
BT2: BAT; cr2032_04_3025-2
C1: 47uF/16V; CP_Radial_D6.3mm_P2.50mm
C2: 10nF; C_Disc_D5.0mm_W2.5mm_P2.50mm
D1: Red; LED-5MM_left
D2: Red; LED-5MM_right
G1: Logo_MA; MA_LOGO
G2: Pin; MTG_2mm
G3, G4, G5, G6, G7, G8: LEG; MTG_1mm
G9: STING; MTG_0mm8
G10: OPEN_HARDWARE_1; Logo_silk_OSHW_6x6mm
J1: JST2; JST_EH_B2B-EH-A_1x02_P2.50mm_Vertical
JP1: Jumper; SolderJumper-2_P1.3mm_Bridged2Bar_RoundedPad1.0x1.5mm
M1: Motor; motor_XDCR_C0720B001F
Q1: BC547; TO-92L_Wide
R1, R2: 220E; r_0805
R3: 47E; r_0805
R4: 1k; r_0805
R5: 33k; r_0805
R6: 10k; r_0805
SW1: On; SW_SPDT_Straight
U1: LM555; DIP-8_W7.62mm

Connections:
/6V: Q1.1 (C), R4.2, SW1.1 (A), U1.4 (R), U1.8 (VCC)
/GND: BT1.2 (-), BT2.2 (-), C1.2, C2.2, J1.1, R1.1, R2.1, R3.1, U1.1 (GND)
/left_eye: D1.2 (K), R1.2
/motor: M1.2 (-), R3.2
/right_eye: D2.2 (K), R2.2
unnamed: BT1.1 (+), BT2.1 (+), J1.2, SW1.2 (B)
unnamed: C1.1, JP1.1 (A), R6.1, U1.2 (TR), U1.6 (THR)
unnamed: C2.1, U1.5 (CV)
unnamed: D1.1 (A), D2.1 (A), M1.1 (+), Q1.3 (E)
unnamed: JP1.2 (B), Q1.2 (B), R5.1
unnamed: R4.1, R6.2, U1.7 (DIS)
unnamed: R5.2, U1.3 (Q)

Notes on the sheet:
Battery Holder 2x2032 with switch BT2 is alternate footprint J1 is for external supply
LEGS solder stiff copper wire pieces to form six legs
STING solder short wire for sting

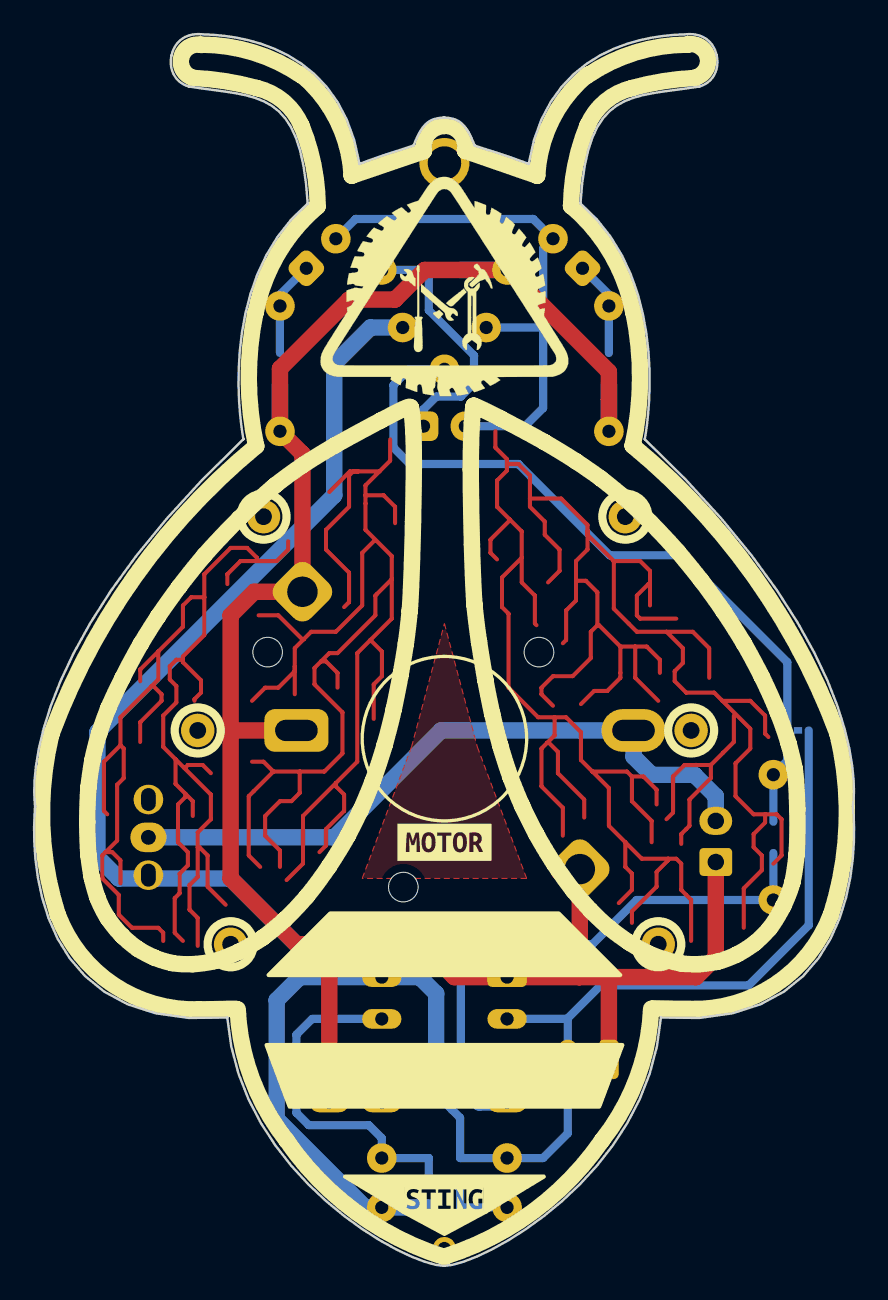
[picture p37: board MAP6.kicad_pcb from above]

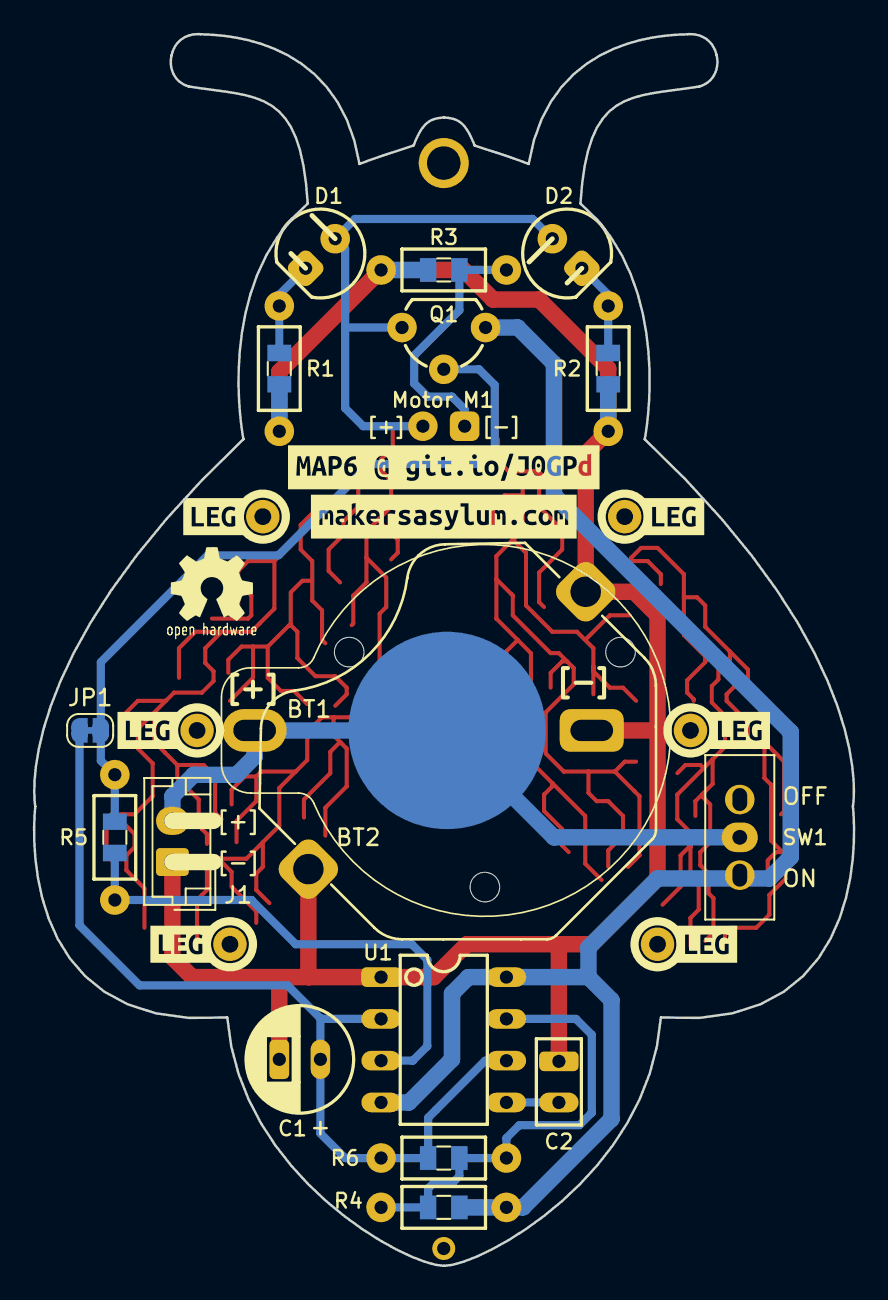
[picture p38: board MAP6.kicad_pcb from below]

Board: 2 copper layers, 49.9 x 74.9 mm, 38 parts (32 on the bottom side), 12 nets.

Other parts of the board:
kibuzzard-611CD92E: G***; label_website
kibuzzard-611CDC95, kibuzzard-611CDC95#2, kibuzzard-611CDC95#3, kibuzzard-611CDC95#4, kibuzzard-611CDC95#5, kibuzzard-611CDC95#6: G***; label_LEG
kibuzzard-611CE09C: G***; label_sting
kibuzzard-611CF906: G***; label_URL
kibuzzard-612E1065: G***; label

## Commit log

2021-08-18 M19O2 MAP6 initial commit
    [BATTERY_HOLDER_CR2032.step, C0720B001F.step, CP_Radial_D6.3mm_P2.50mm.step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]
2021-08-18 M19O2 MAP6 added .STEP CAD file
    [MAP6.kicad_pcb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]
2021-08-18 M19O2 MAP6 cleaned SILK legend
    [MAP6-B_Cu.gbr, MAP6-B_Mask.gbr, MAP6-B_SilkS.gbr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]
2021-08-23 MAP6 Blender renders and amimations
    [CP_Radial_D6.3mm_P2.50mm.step, CP_Radial_D63mm_P250mm.step, CP_Radial_D63mm_P250mm_FC.step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]
2021-08-24 added interactive HTML BoM in /bom folder
    [MAP6.kicad_pcb, MAP6.sch, MAP6_BoM.xls]
2021-08-31 updated schematic and pcb
    [BATTERY_HOLDER_CR2032.step, CP_Radial_D63mm_P250mm.step, CP_Radial_D63mm_P250mm_FC.step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]
2021-09-06 Create readme.md
    added link for online BoM
2021-09-07 big update, added several battery options
    [2x2032_cyl.FCStd, 2x2032_cyl.step, BH800S--56544.step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]
2021-09-08 another big update after deciding battery options. Ready for FAB
    [2x2032_cyl.FCStd, 2x2032_cyl.step, CR2032_3025-2.step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]
2021-10-22 added assembly images in /fabricate folder
    [MAP6_CAD2.FCStd]
2023-02-06 added production files folder, LCSC BoM
    [BH800S--56544.step, BH800S.step, C0720B001F.step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]

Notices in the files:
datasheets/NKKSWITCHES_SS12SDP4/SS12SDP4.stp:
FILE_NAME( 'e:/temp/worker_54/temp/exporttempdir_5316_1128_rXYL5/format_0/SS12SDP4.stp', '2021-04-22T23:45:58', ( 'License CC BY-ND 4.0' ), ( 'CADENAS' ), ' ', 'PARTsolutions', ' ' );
